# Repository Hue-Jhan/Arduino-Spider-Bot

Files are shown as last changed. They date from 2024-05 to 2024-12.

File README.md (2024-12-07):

# Arduino-Spider-Bot
Arduino-based SpiderBot, remotely controllable, with obstacle detection and automated walk. Inspired by TokyoBird but with lots of changes. ⚡ NEW UPDATE: Now the robot comes with a super-cool 50.000 volts taser!!! 

# 🔋 Parts and Robotics


The 3d files are located in the `3d files` folder. \
Other parts:
- 8 servo motors (90° degrees position)
- Ultrasonic sensor HC-SR04
- Arduino Nano + Arduino Nano expansion board
- Bluetooth Module Hc-05
- Jumpers, screws n other stuff
- 2 Lithium Batteries (+ case)
- Buck Converter (+ ammeter)
- High voltage generator (5-8v input : 50.000v output)
- Small relay

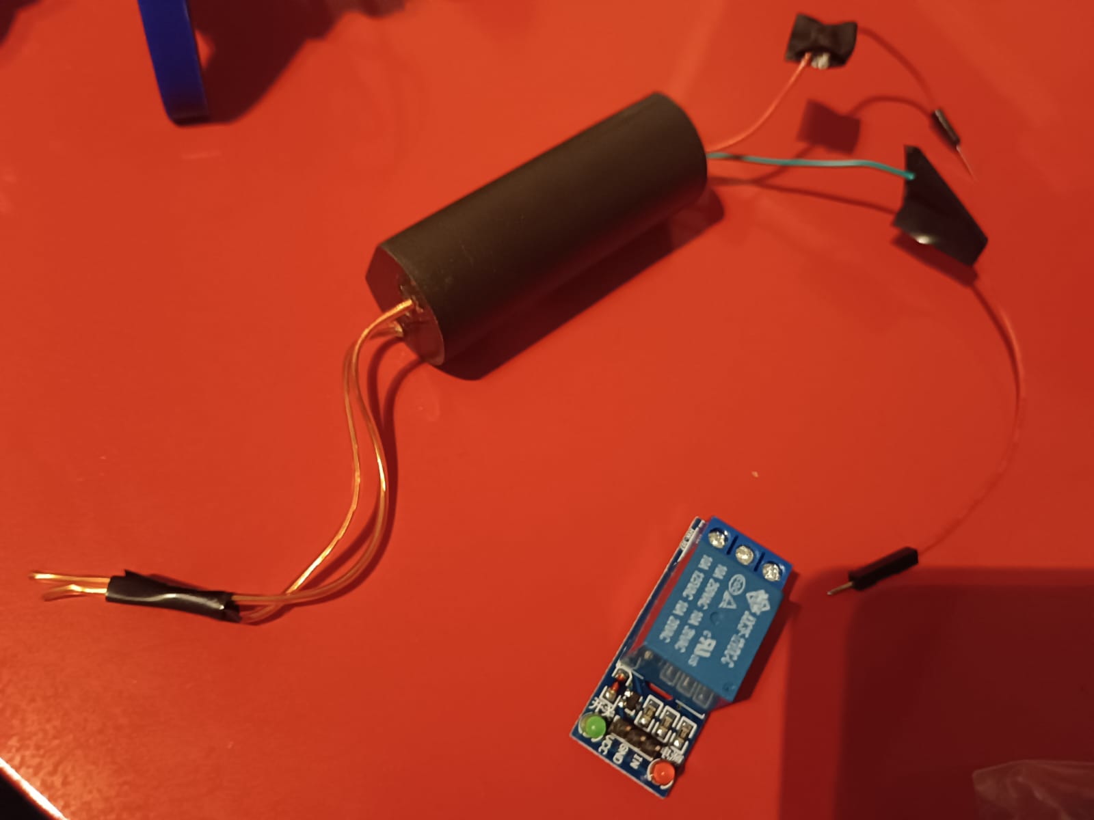
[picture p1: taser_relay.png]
How to build: simply follow the instructions on [TokyoBird](https://www.thingiverse.com/thin:4905975)'s page.  \
Here are the changes i've made: 
- I used the HC-05 module to send commands instead of the Serial Monitor.
- I attached a Taser to it, i can use it whenever i want to. pic of it + relay to the right ---> 
- I used 2 lithium batteries soldered to a buck converter (the output is set to 5v, but if the batteries are 3.7v each you technically should be able to ignore the buck converter and attach the batteries directly to the board), my batteires were 4.2v each so i preferred to use the converter.
- I updated the code to make it easily compatible with Bluetooth app ([this one](https://play.google.com/store/apps/details?id=com.giumig.apps.bluetoothserialmonitor&hl=en&gl=US&pli=1)).
- Because the servos i used are not original, the fins are too big to fit in the 3d printed legs, so i used my soldering iron to make the gaps bigger and i fixed the fins with some tape, although glue would be better.
- I added a shell to cover all the cables (u can find it in the 3d print files folder).
- Modified some animations to avoid issued related to voltage supply and current, i noticed that if the bot is not powered by batteries (so simply by pc cable) there can be current shortages mid-animations, so i amplified some delays and made some changes.

# 💻 Code

The **`first code`** is quite simple, every second or so the hc05 bluetooth module checks for input to send to the robot, it serial prints them (for debugging purposes) and sends the data to the robot which will execute the animations. 
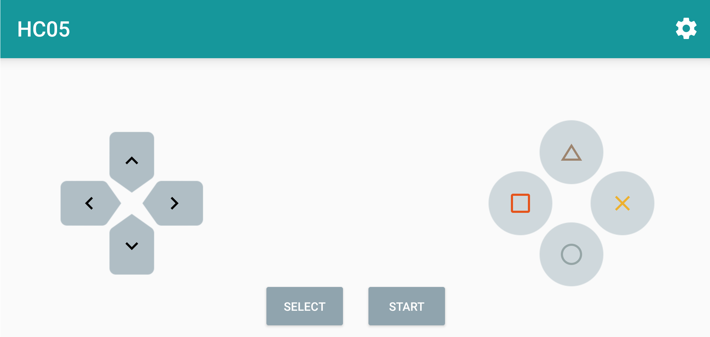
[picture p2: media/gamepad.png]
Unfortunately there is no way to make the walking animation possible using a joystick, as the walking functions are not simple motors but complex things. The only way to use it is to push the Walk Forward button every time.... yeah its annoying but its all i can do. I customized the buttons on the right: 
- Triangle: wink animation, the robot says hello
- Square: sit animationn, the bot slowly sits and goes back up 
- Circle: twist animation, the bot twists all its legs in and out 
- X: sit2 animation, the robot sits (and doesnt stand up)
- Select: uses taser

The **`second code`** is the automated walk code, it uses the ultrasonic sensor to see if anything is in a range of a few centimiters, and if there is, the robots slowly backs up and changes direction. \
Here is a video showcasing it, i didnt solder the batteries yet so it was powered by the pc

https://github.com/Hue-Jhan/Arduino-Spider-Bot/assets/75088696/948d0f76-3dea-49bb-976c-75f6bf47370e

# ⚡ Taser

Using a relay i can remotely activate a 50k volts high voltage generator, it uses the same lithium batteries as the other components, its activated by the Select Button on the Android Bluetooth controller app. Do not use it against electronic components or else they might get damaged, and by the way it hurts, a lot.

https://github.com/user-attachments/assets/529a7c71-5bb1-40c3-ae3d-1470e08477f8
> [!CAUTION]  
> Remember to insert a switch between the battery case and the dc converter or othwerise it will **blow up** due to overheating, as the buck converter always tries to "get" current from the batteries

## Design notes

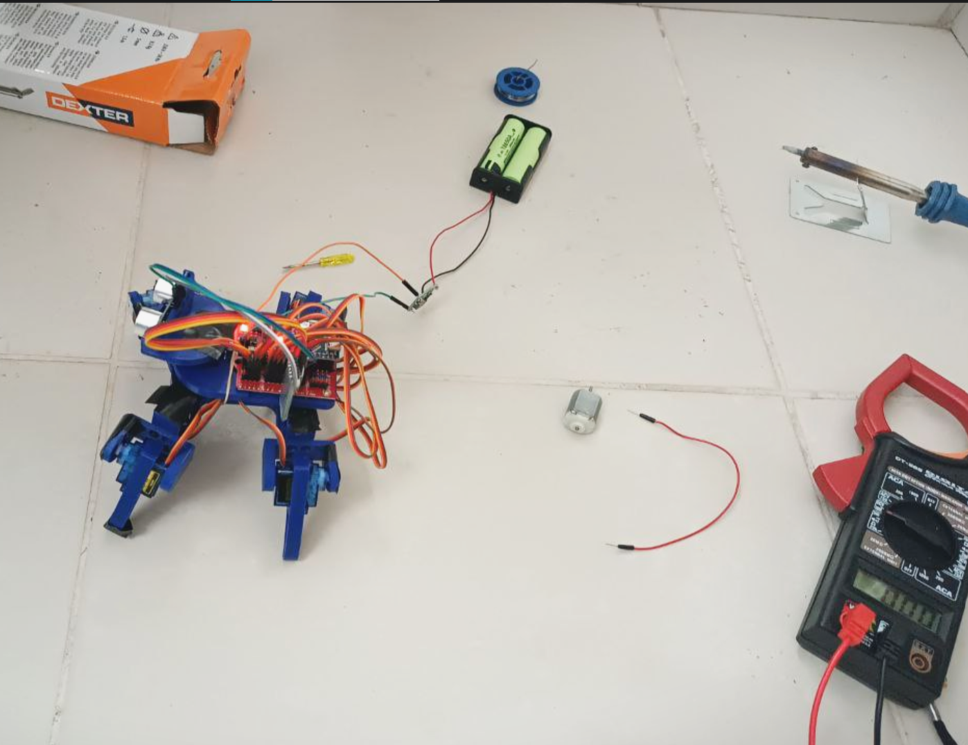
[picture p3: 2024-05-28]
media/c.png

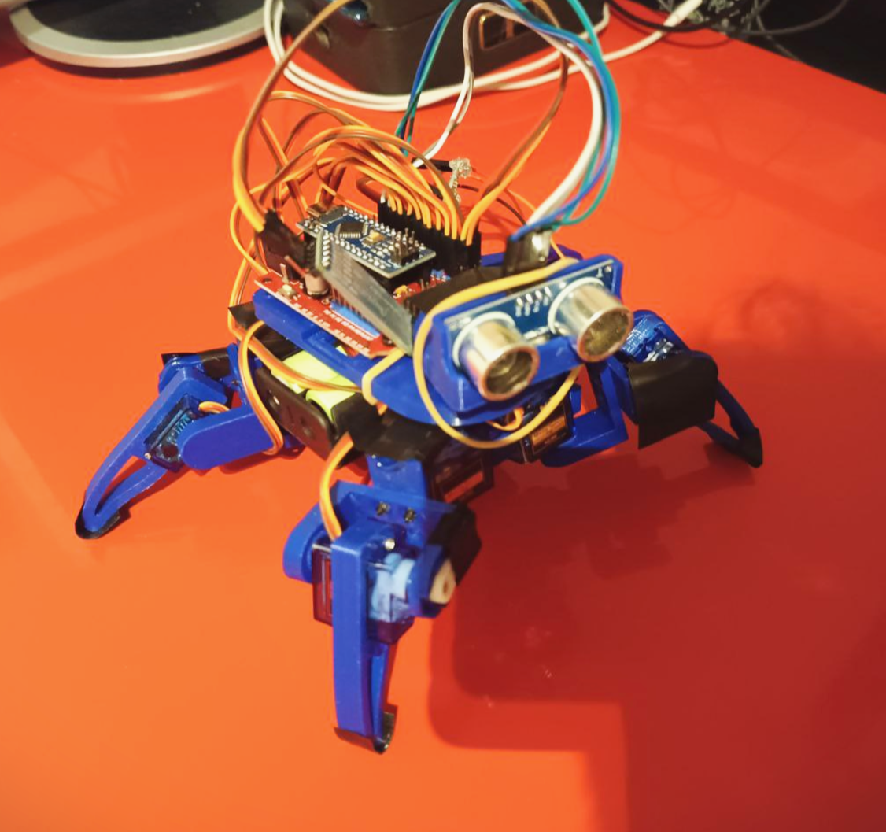
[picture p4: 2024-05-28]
media/b.png

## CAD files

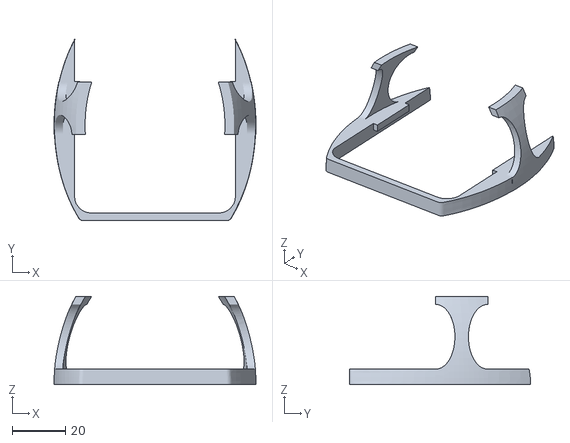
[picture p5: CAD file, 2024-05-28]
3d files/Shell_Base.stl
75.7 x 67.9 x 33.1

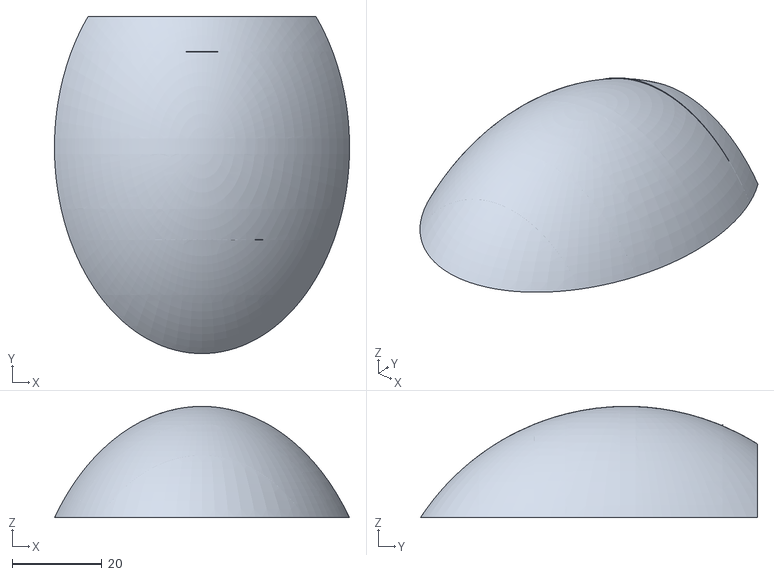
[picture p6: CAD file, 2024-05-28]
3d files/Shell.stl
65.8 x 75.2 x 24.8

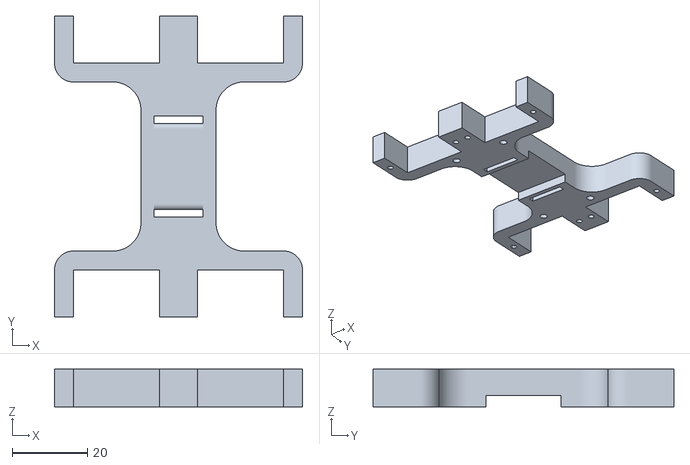
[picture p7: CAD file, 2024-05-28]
3d files/body1.stl
66.0 x 80.0 x 10.0

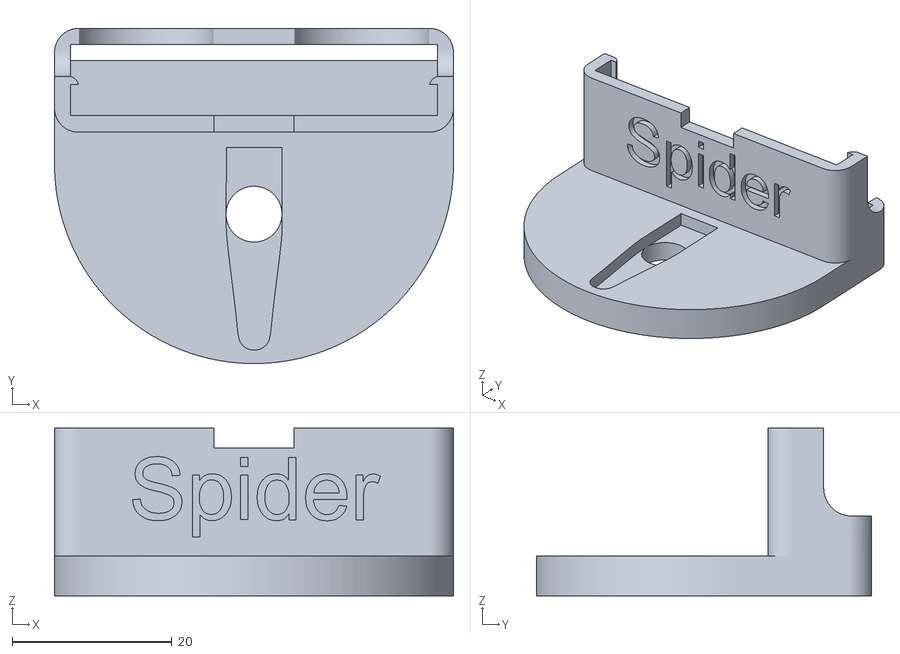
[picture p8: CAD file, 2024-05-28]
3d files/hc_sr04_mount.stl
50.0 x 42.0 x 21.0

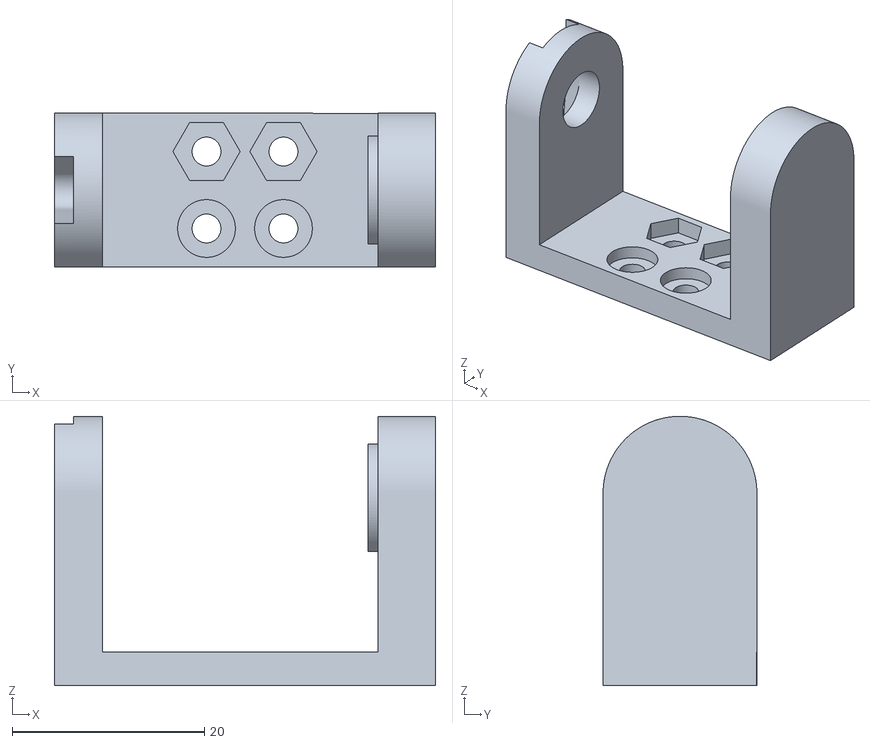
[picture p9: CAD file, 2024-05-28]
3d files/center_arm.stl
39.6 x 16.0 x 28.0

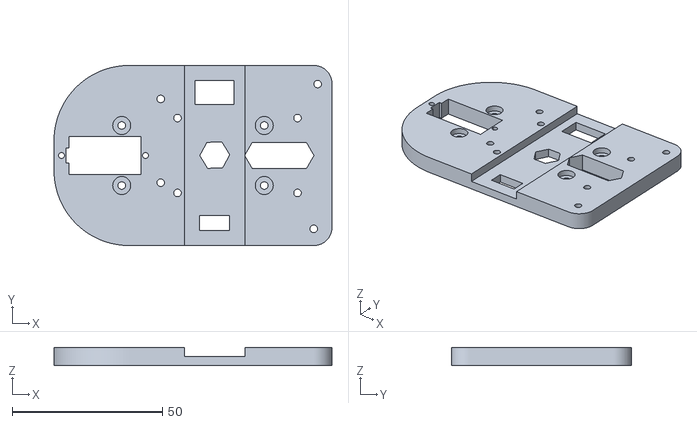
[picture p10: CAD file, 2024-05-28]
3d files/body2.stl
92.6 x 60.0 x 6.00

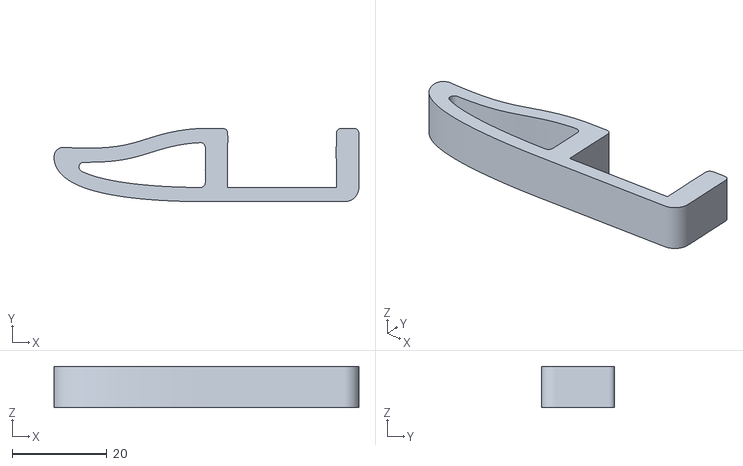
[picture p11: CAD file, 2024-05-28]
3d files/left_arm.stl
64.5 x 15.5 x 8.73

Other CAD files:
3d files/right_arm.stl

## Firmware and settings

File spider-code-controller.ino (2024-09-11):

#include <Servo.h>
#include <SoftwareSerial.h>
SoftwareSerial hc05(0, 1);

Servo joint2;
Servo joint3;
Servo joint4;  
Servo joint5;  
Servo joint6;  
Servo joint7;  
Servo joint8;  
Servo joint9;  
Servo neck_servo;  
int home_joint2 = 120;
int home_joint3 = 15;
int home_joint4 = 60;
int home_joint5 = 165;
int home_joint6 = 100;
int home_joint7 = 15;
int home_joint8 = 70;
int home_joint9 = 165;
#define neck_survoPin 10
#define trigPin 11
#define echoPin 12
float Dulation, Distance, sum = 0;
int angle = 90;

void setup(){
  Serial.begin(9600);
  Serial.println("Enter comand: ");
  hc05.begin(9600);
  delay(1000);

  joint2.attach(2);
  joint3.attach(3);
  joint4.attach(4);
  joint5.attach(5);
  joint6.attach(6);
  joint7.attach(7);
  joint8.attach(8);
  joint9.attach(9);
  neck_servo.attach(neck_survoPin, 500, 2400);
  neck_servo.write(90);
  pinMode(echoPin,INPUT);
  pinMode(trigPin,OUTPUT);
  joint2.write(home_joint2);
  joint3.write(home_joint3);
  joint4.write(home_joint4);
  joint5.write(home_joint5);
  joint6.write(home_joint6);
  joint7.write(home_joint7);
  joint8.write(home_joint8);
  joint9.write(home_joint9);
  // standhome();
  // sithome();
  delay(1000);  }

bool moving = false;

void loop() {
  unsigned long currentTime = millis();
  if (hc05.available() > 0) {
    char data = hc05.read();
    execute(data);
    Serial.print(data);
  }
}

void execute(char data) {
  switch (data) {
    case 'F':
      forward(2);
      break;
    case 'v':
      Serial.println("bals xdd");
      break;
    case 'B':
      backward(2);
      break;
    case 'R':
      rightturn(2);
      break;
    case 'L':
      leftturn(2);
      break;
    case 'T':
      wink(2);
      break;
    case 'S':
      sithome();
      break;
    case 'C':
      twist();
      break;
    case 'X':
      stand1();
      break;
    case 'S':
      digitalWrite(13, HIGH);
      delay(500);
      digitalWrite(13, LOW);
      break;
    default:
      Serial.println("error xd");
      break;
  }
}
  /* if (Serial.available() > 0) {
    char data = Serial.read();
    Serial.print(data);
    if (data == 'F') { 
      forward(2);  }
    else if (data == 'v') {
      Serial.println("bals xdd"); }
    else if (data == 'B') {
      backward(2); }
  }   */

void sithome(){
    joint2.write(135);
    delay(200);
    joint3.write(65);
    delay(200);
    joint4.write(45);
    delay(200);
    joint5.write(110);
    delay(200);
    joint6.write(135);
    delay(200);
    joint7.write(80);
    delay(200);
    joint8.write(45);
    delay(200);
    joint9.write(110);
    delay(200); }

void idle(){
  delay(100); }

void standhome(){
  joint2.write(home_joint2);
  delay(200);
  joint3.write(home_joint3);
  delay(200);
  joint4.write(home_joint4);
  delay(200);
  joint5.write(home_joint5);
  delay(200);
  joint6.write(home_joint6);
  delay(200);
  joint7.write(home_joint7);
  delay(200);
  joint8.write(home_joint8);
  delay(200);
  joint9.write(home_joint9);
  delay(200); }

void stand1(){
  sithome();
  joint2.write(170);
  delay(400);
  joint2.write(home_joint2);
  delay(400);
  joint4.write(10);
  delay(400);
  joint4.write(home_joint4);
  delay(400);
  joint6.write(170);
  delay(400);
  joint6.write(home_joint6);
  delay(400);
  joint8.write(10);
  delay(400);
  joint8.write(home_joint8);
  delay(400);
  joint3.write(home_joint3);
  delay(200);
  joint5.write(home_joint5);
  delay(200);
  joint7.write(home_joint7);
  delay(200);
  joint9.write(home_joint9);
  delay(200); }

void neckrotate(){
  int i=90;
  while(i < 150){
    neck_servo.write(i);
    i++;
    delay(5); }
  while(i > 30){
    neck_servo.write(i);
    i--;
    delay(5); }
  while(i <= 90){
    neck_servo.write(i);
    i++;
    delay(5); }
}

void forward(unsigned int step){
 // while (isPressed) {
 //  while (step-- >= 0){
  joint3.write(home_joint3+30);
  joint7.write(home_joint7+30);
  delay(100);
  joint2.write(home_joint2+30);
  joint8.write(home_joint8-30);
  joint4.write(home_joint4);
  joint6.write(home_joint6);
  delay(100);
  joint3.write(home_joint3);
  joint7.write(home_joint7);
  idle();
  
  joint5.write(home_joint5-30);
  joint9.write(home_joint9-30);
  delay(100);
  joint2.write(home_joint2);
  joint8.write(home_joint8);
  joint4.write(home_joint4-30);
  joint6.write(home_joint6+30);
  delay(100);
  joint5.write(home_joint5);
  joint9.write(home_joint9);
  idle();
  // } }
}

void backward(unsigned int step){
  while (step-- > 0){
  joint3.write(home_joint3+30);
  joint7.write(home_joint7+30);
  delay(100);
  joint2.write(home_joint2);
  joint8.write(home_joint8);
  joint4.write(home_joint4-30);
  joint6.write(home_joint6+30);
  delay(100);
  joint3.write(home_joint3);
  joint7.write(home_joint7);
  idle();
  
  joint5.write(home_joint5-30);
  joint9.write(home_joint9-30);
  delay(100);
  joint2.write(home_joint2+30);
  joint8.write(home_joint8-30);
  joint4.write(home_joint4);
  joint6.write(home_joint6);
  delay(100);
  joint5.write(home_joint5);
  joint9.write(home_joint9);
  idle();
  }
}

void rightturn(unsigned int step){
  while (step-- > 0){
  joint5.write(home_joint5-30);
  joint9.write(home_joint9-30);
  delay(100);
  joint2.write(home_joint2+30);
  joint8.write(home_joint8-30);
  joint4.write(home_joint4-30);
  joint6.write(home_joint6+30);
  delay(100);
  joint5.write(home_joint5);
  joint9.write(home_joint9);
  idle();
  
  joint3.write(home_joint3+30);
  joint7.write(home_joint7+30);
  delay(100);
  joint2.write(home_joint2);
  joint8.write(home_joint8);
  joint4.write(home_joint4);
  joint6.write(home_joint6);
  delay(100);
  joint3.write(home_joint3);
  joint7.write(home_joint7);
  idle();
  }
}

void leftturn(unsigned int step){
  while (step-- > 0){
  joint3.write(home_joint3+30);
  joint7.write(home_joint7+30);
  delay(100);
  joint2.write(home_joint2+30);
  joint8.write(home_joint8-30);
  joint4.write(home_joint4-30);
  joint6.write(home_joint6+30);
  delay(100);
  joint3.write(home_joint3);
  joint7.write(home_joint7);
  idle();
  
  joint5.write(home_joint5-30);
  joint9.write(home_joint9-30);
  delay(100);
  joint2.write(home_joint2);
  joint8.write(home_joint8);
  joint4.write(home_joint4);
  joint6.write(home_joint6);
  delay(100);
  joint5.write(home_joint5);
  joint9.write(home_joint9);
  idle();
  }
}

void neck_leftrotate(){
  int i=90;
  while(i < 150){
    neck_servo.write(i);
    i++;
    delay(5); } }
void neck_rightrotate(){
  int i=90;
  while(i > 30){
    neck_servo.write(i);
    i--;
    delay(5);  }  }
void neck_home(){
  neck_servo.write(90);
}

void twist(){
  joint3.write(home_joint3);
  joint5.write(home_joint5);
  joint7.write(home_joint7);
  joint9.write(home_joint9);
  for(int right=90;right<170;right++){
      joint2.write(right);
      joint6.write(right);
      joint4.write(right-90);
      joint8.write(right-90);
      delay(10);  }
   for(int right=170;right>90;right--){
      joint2.write(right);
      joint6.write(right);
      joint4.write(right-90);
      joint8.write(right-90);
      delay(10);  }
}

void wink(unsigned int step){
  standhome();
  joint9.write(home_joint9-30); 
  while (step-- > 0){
  joint5.write(30);
  joint4.write(home_joint4 + 60);
  delay(300);
  joint4.write(home_joint4 - 60);
  delay(300);  }
}
